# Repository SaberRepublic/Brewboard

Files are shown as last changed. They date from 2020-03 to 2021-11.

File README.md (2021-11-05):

# Brewboard
PCB files for the Saber Republic Brewboard

Format is EagleCAD schematic, board layout, and library 

Brewboard is a carrier board for an Arduino Nano, DFPlayer and GY-521 accelerometer. It is designed to make it easy and cheap to build a homebrew soundboard for your saber or other custom props. While it's not as small as other choices on the market it is cheap fully opensource and full-featured. You can use different firmware solutions or roll your own.

 - Connects Arduino Nano, DFPlayer, and GY-521
 - Supports Neo-Pixel and RGB/RGBW Star LEDs and string blades* (with added MOSFETs and resitors)
 - Uses 0805 resitors and sot23 MOSFETs to keep it's footprint small.

You can direct order a board from here:
[Saber Republic](https://saberrepublic.bigcartel.com)

Model Can be viewed and downloaded here:
[Brewboard model](https://sketchfab.com/3d-models/brewboard-v401-b3-2d1b7a565fd34a01af89348552af9d3d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)

There two choices for firmware:

[FX-SaberOS (opensource)](https://github.com/Protonerd/FX-SaberOS)

[STREAM (closedsource but very user friendly)](https://github.com/JakeS0ft/STREAM)

This is a video demo of Brewboard V2 in action.

Brewboard V2 (https://www.youtube.com/watch?v=12ZV0RvzIn0)

V2 Pinout diagrams.

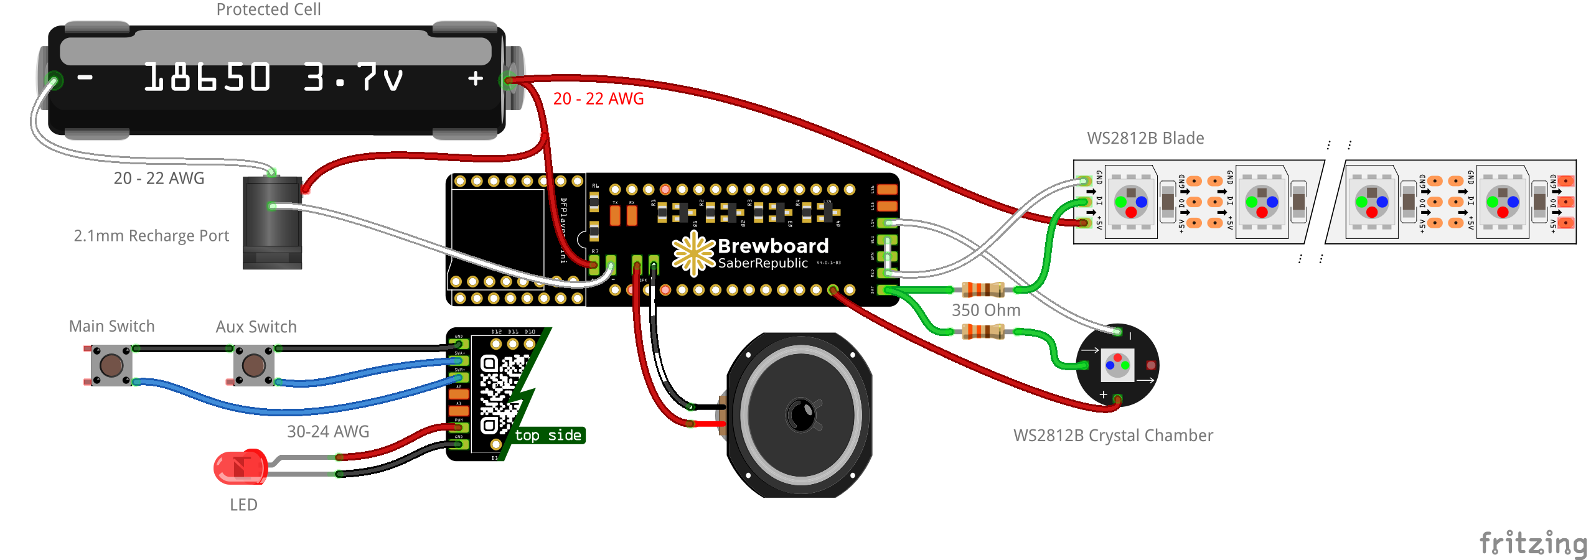
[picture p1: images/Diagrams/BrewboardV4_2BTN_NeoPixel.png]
NeoPixel Pinout


For more diagrams and Info Check the [Wiki](https://github.com/SaberRepublic/Brewboard/wiki)

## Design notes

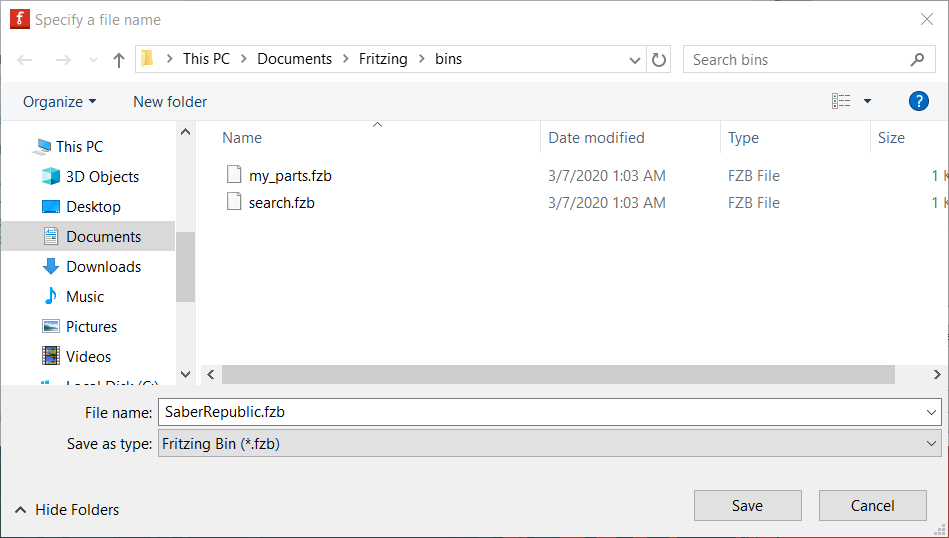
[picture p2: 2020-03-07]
images/Fritzing/5_SpecifyFileName.png

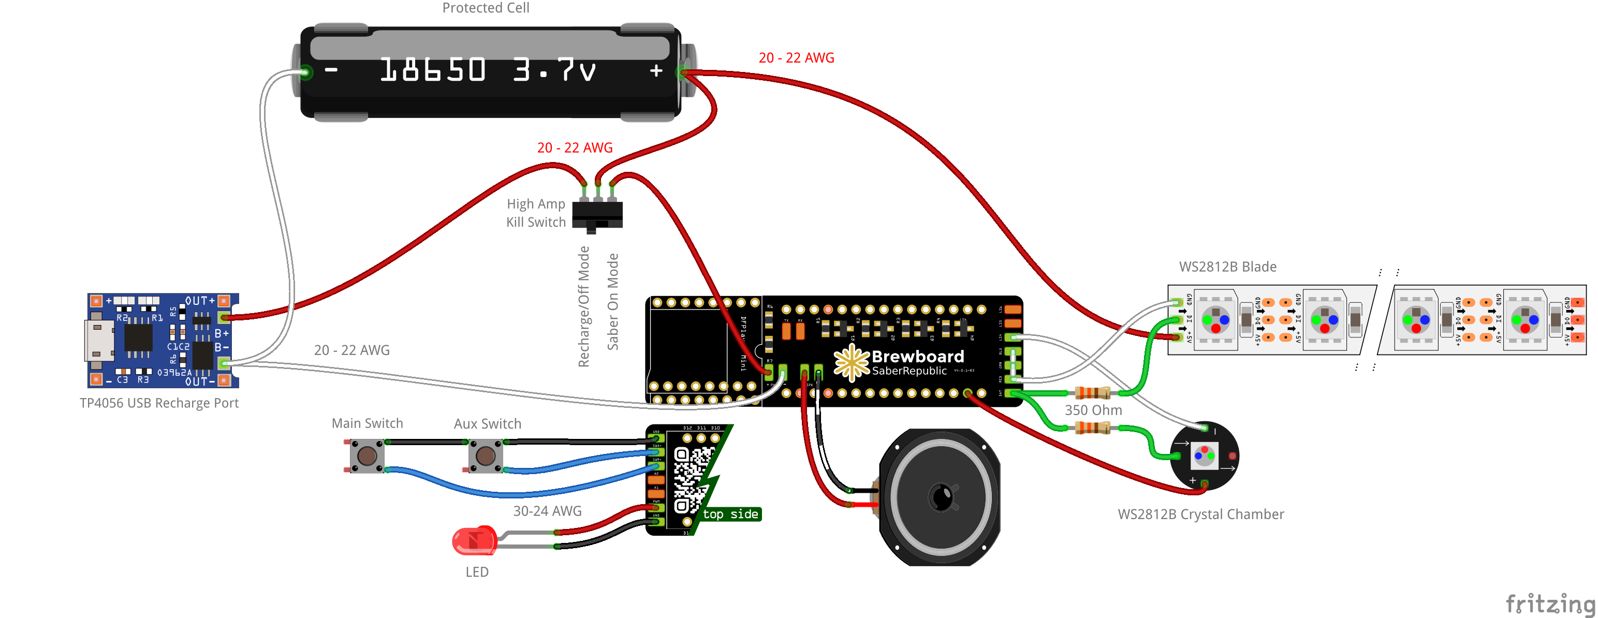
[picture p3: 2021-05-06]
images/Diagrams/BrewboardV4_2BTN_NeoPixel_TP4056.png

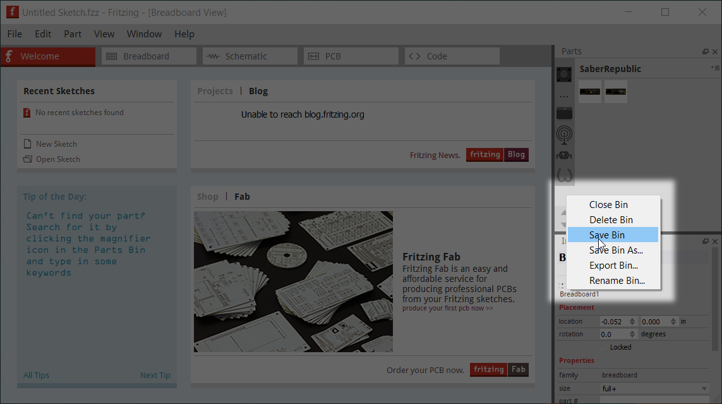
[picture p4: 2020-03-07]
images/Fritzing/4_SaveBin.png

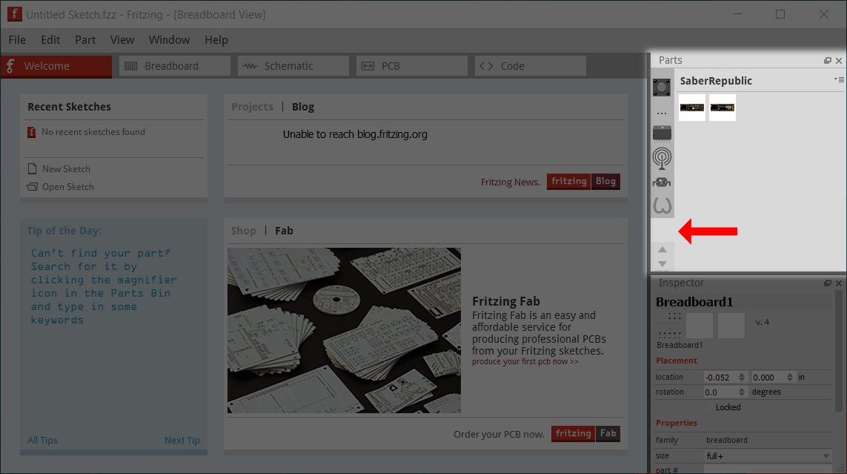
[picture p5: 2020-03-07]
images/Fritzing/3_BinLoaded.png

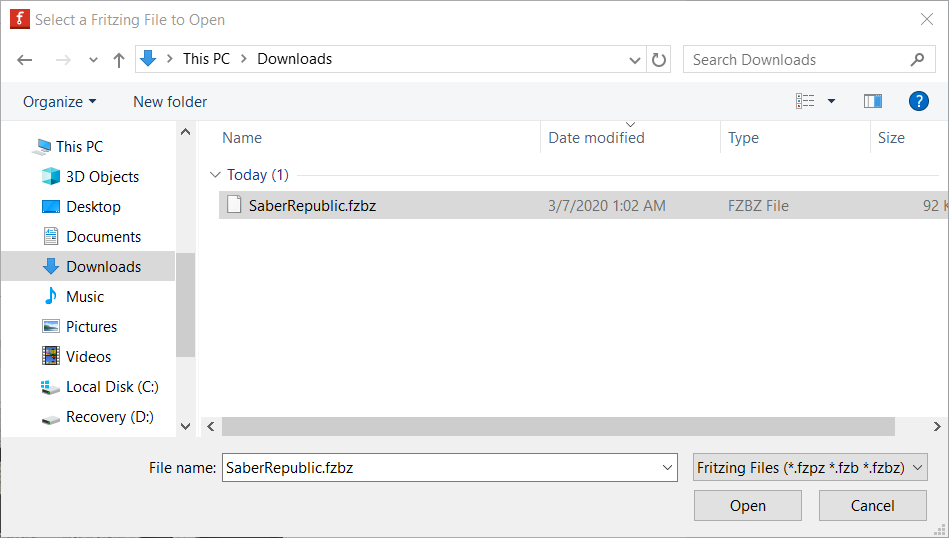
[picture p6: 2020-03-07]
images/Fritzing/2_SelectFritzingFiletoOpen.png

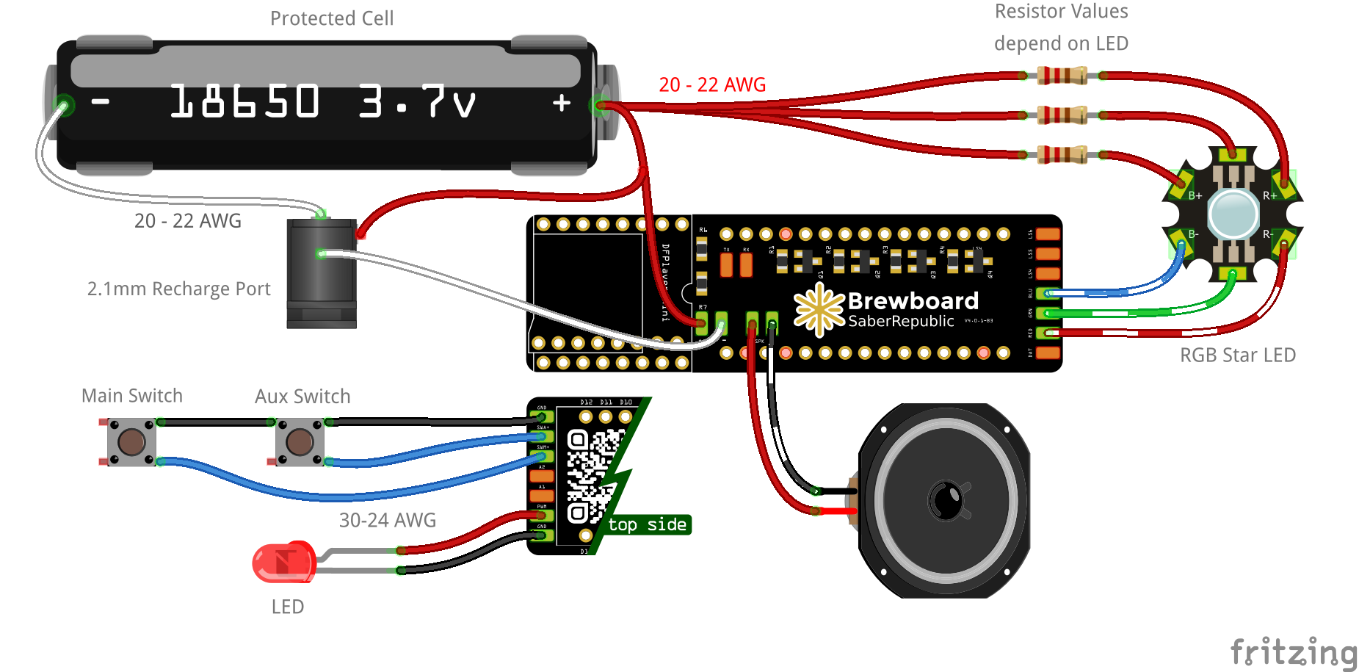
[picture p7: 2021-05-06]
images/Diagrams/BrewboardV4_2BTN_Star.png

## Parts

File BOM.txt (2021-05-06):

+-----+-----------------+----------------+---------+--------------------+---------------------------+
| Qty |      Value      |     Device     | Package |       Parts        |        Description        |
+-----+-----------------+----------------+---------+--------------------+---------------------------+
|   5 | 100k Ohms       | R-US_R0805     | R0805   | R1, R2, R3, R4, R6 | RESISTOR, American symbol |
|   1 | 470k Ohms       | R-US_R0805     | R0805   | R7                 | RESISTOR, American symbol |
|   4 | si2302cds-t1-e3 | MOSFET-NREFLOW | SOT23   | Q1, Q2, Q3, Q4     | N-Channel Mosfet          |
+-----+-----------------+----------------+---------+--------------------+---------------------------+

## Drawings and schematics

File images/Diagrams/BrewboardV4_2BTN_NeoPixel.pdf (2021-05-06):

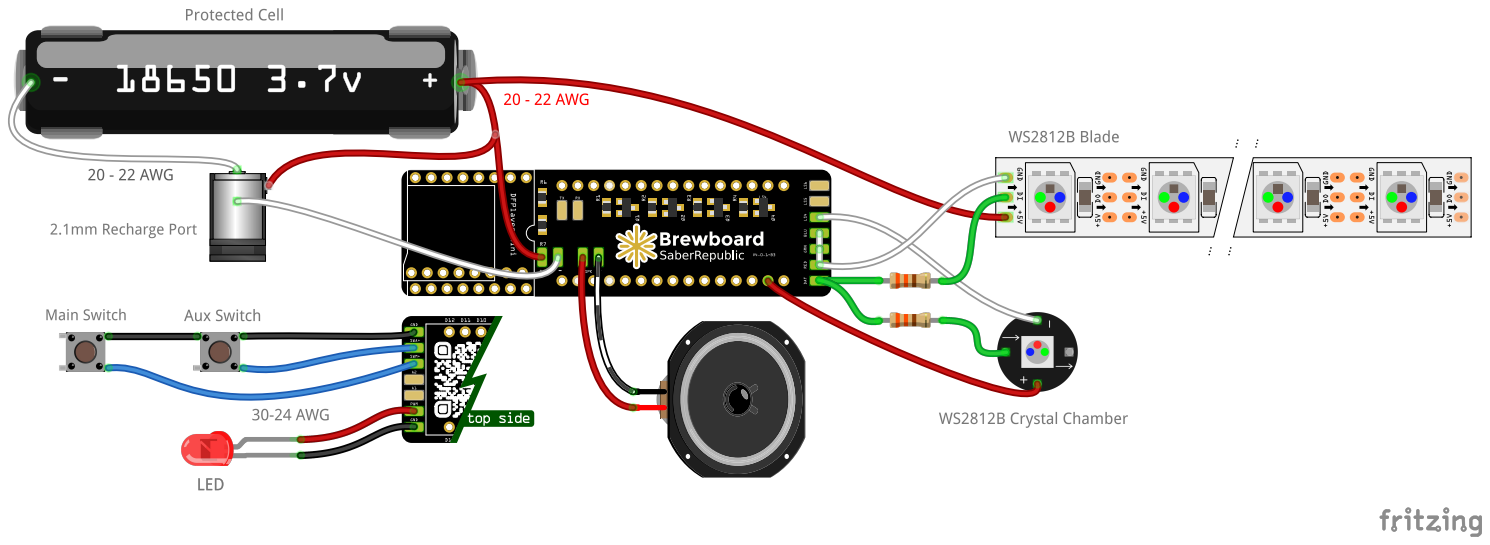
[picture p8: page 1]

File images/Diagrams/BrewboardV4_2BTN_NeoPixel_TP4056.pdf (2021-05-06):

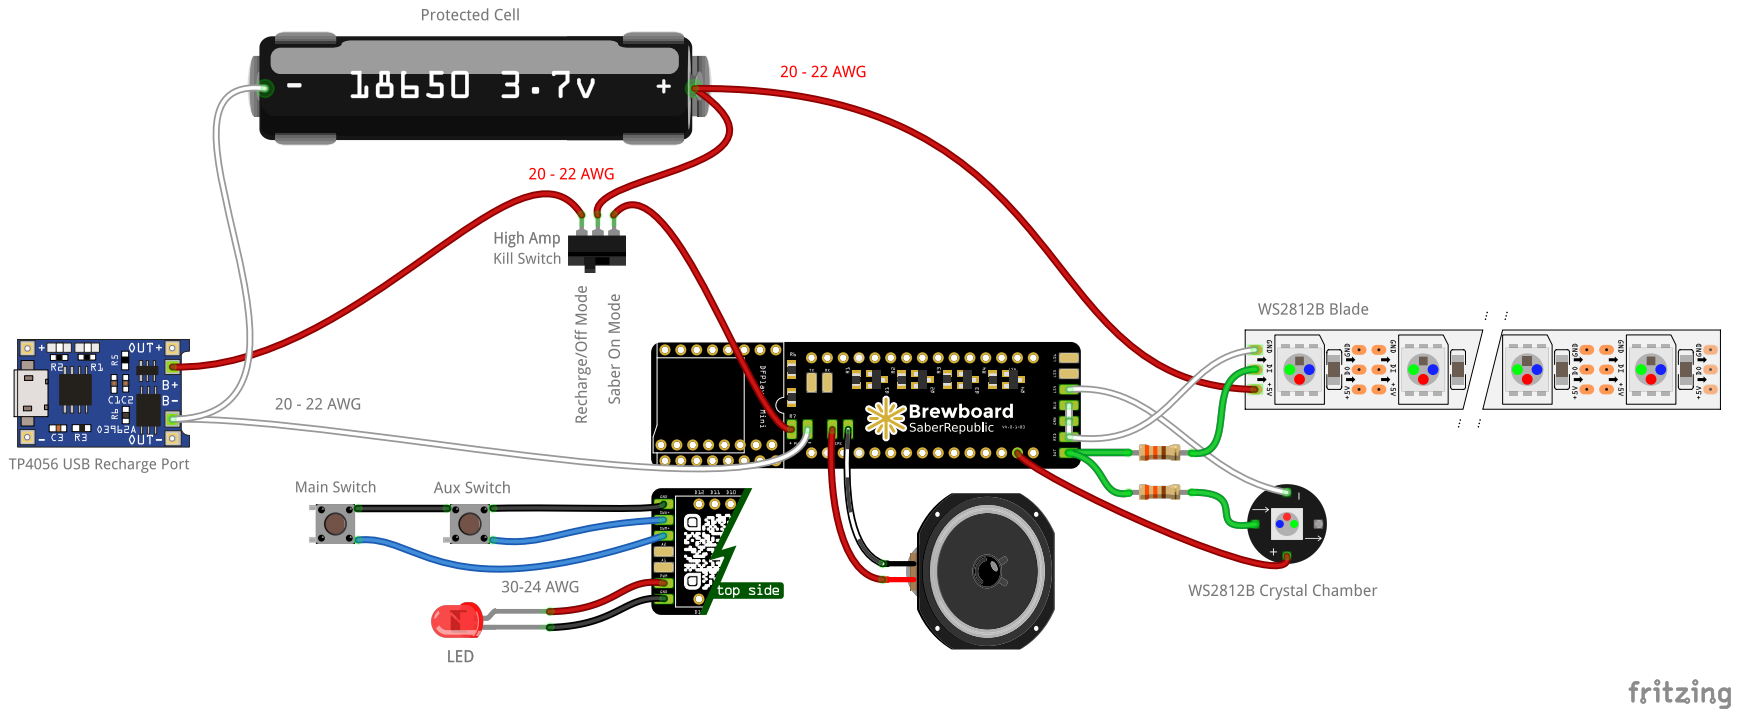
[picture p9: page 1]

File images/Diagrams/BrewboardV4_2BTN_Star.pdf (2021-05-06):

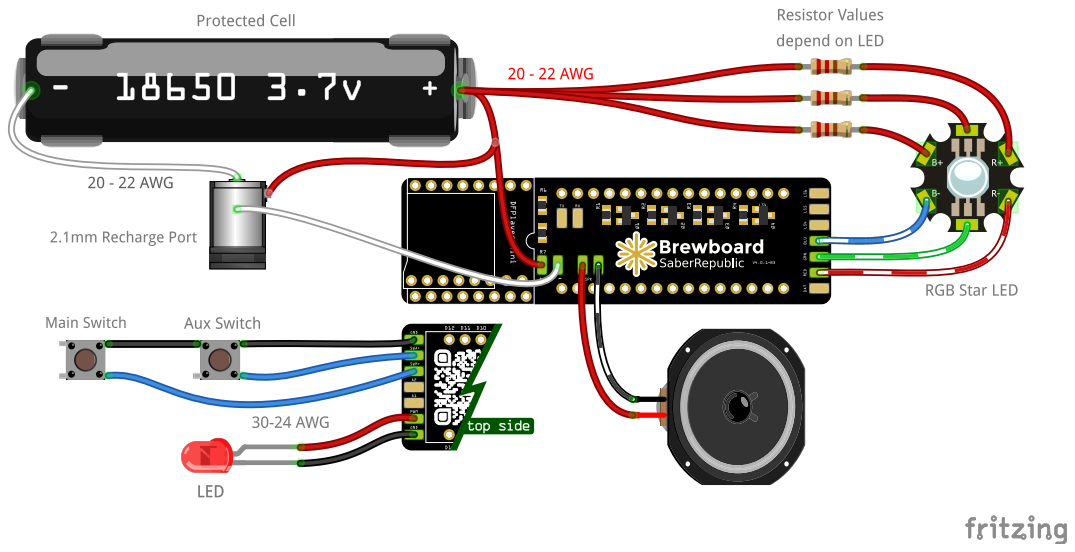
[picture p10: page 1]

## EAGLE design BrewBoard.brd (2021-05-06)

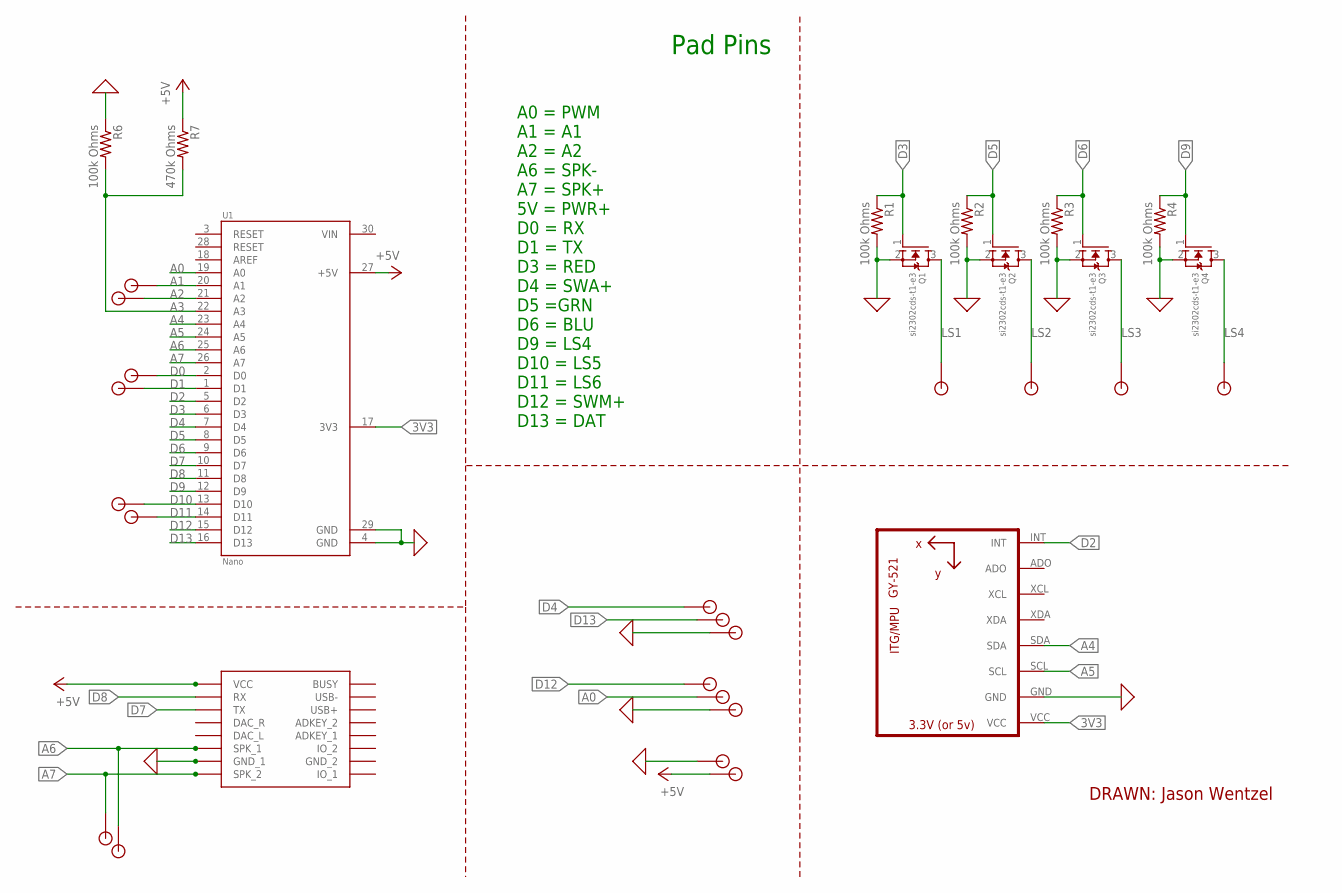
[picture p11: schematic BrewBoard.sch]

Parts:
LS1: SINGLE_ONE_SIDE_PAD; SOS_PAD
Q1, Q2, Q3, Q4: si2302cds-t1-e3; SOT23
R1, R2, R3, R4, R6: 100k Ohms; R0805
R7: 470k Ohms; R0805
SPK+: SINGLE_ONE_SIDE_PAD; SOS_PAD
U1: Nano; ARDUINO_NANO_OUT
U2: GY-521MPU6050; GY-521
U3: DFPLAYER
U$1, U$4, U$5, U$6, U$7, U$8, U$9, U$11, U$12, U$13, U$15, U$16, U$17, U$18, U$19, U$22, U$27, U$28: SINGLE_ONE_SIDE_PAD; SOS_PAD

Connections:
0: Q1.2 (S), Q2.2 (S), Q3.2 (S), Q4.2 (S), R1.2, R2.2, R3.2, R4.2, R6.1, U1.4 (GND), U1.29 (GND), U2.GND, U3.GND_1, U$13.P$1, U$17.P$1, U$27.P$1
3V3: U1.17 (3V3), U2.VCC
+5V: R7.1, U1.27 (+5V), U3.VCC, U$12.P$1
A0: U1.19 (A0), U$18.P$1
A1: U1.20 (A1), U$1.P$1
A2: U1.21 (A2), U$4.P$1
A3: R6.2, R7.2, U1.22 (A3)
A4: U1.23 (A4), U2.SDA
A5: U1.24 (A5), U2.SCL
A6: U1.25 (A6), U3.SPK1 (SPK_1), U$11.P$1
A7: SPK+.P$1, U1.26 (A7), U3.SPK2 (SPK_2)
D0: U1.2 (D0), U$5.P$1
D1: U1.1 (D1), U$6.P$1
D2: U1.5 (D2), U2.INT
D3: Q1.1 (G), R1.1, U1.6 (D3)
D4: U1.7 (D4), U$22.P$1
D5: Q2.1 (G), R2.1, U1.8 (D5)
D6: Q3.1 (G), R3.1, U1.9 (D6)
D7: U1.10 (D7), U3.TX
D8: U1.11 (D8), U3.RX
D9: Q4.1 (G), R4.1, U1.12 (D9)
D10: U1.13 (D10), U$8.P$1
D11: U1.14 (D11), U$9.P$1
D12: U1.15 (D12), U$19.P$1
D13: U1.16 (D13), U$28.P$1
LS1: LS1.P$1, Q1.3 (D)
LS2: Q2.3 (D), U$15.P$1
LS3: Q3.3 (D), U$16.P$1
LS4: Q4.3 (D), U$7.P$1
VIN: U1.30 (VIN)

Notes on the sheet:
DRAWN: Jason Wentzel
Pad Pins
A0 = PWM A1 = A1 A2 = A2 A6 = SPK- A7 = SPK+ 5V = PWR+ D0 = RX D1 = TX D3 = RED D4 = SWA+ D5 =GRN D6 = BLU D9 = LS4 D10 = LS5 D11 = LS6 D12 = SWM+ D13 = DAT

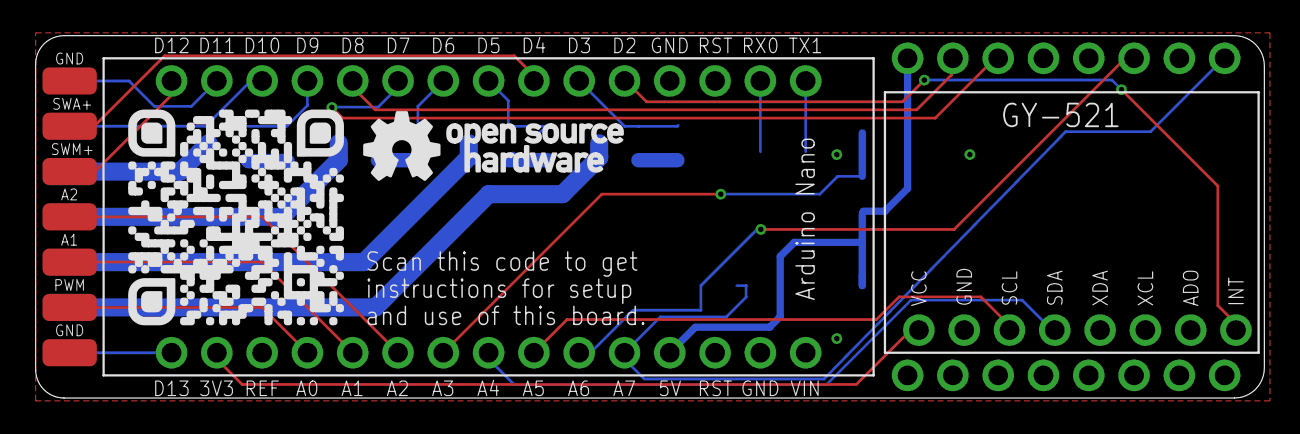
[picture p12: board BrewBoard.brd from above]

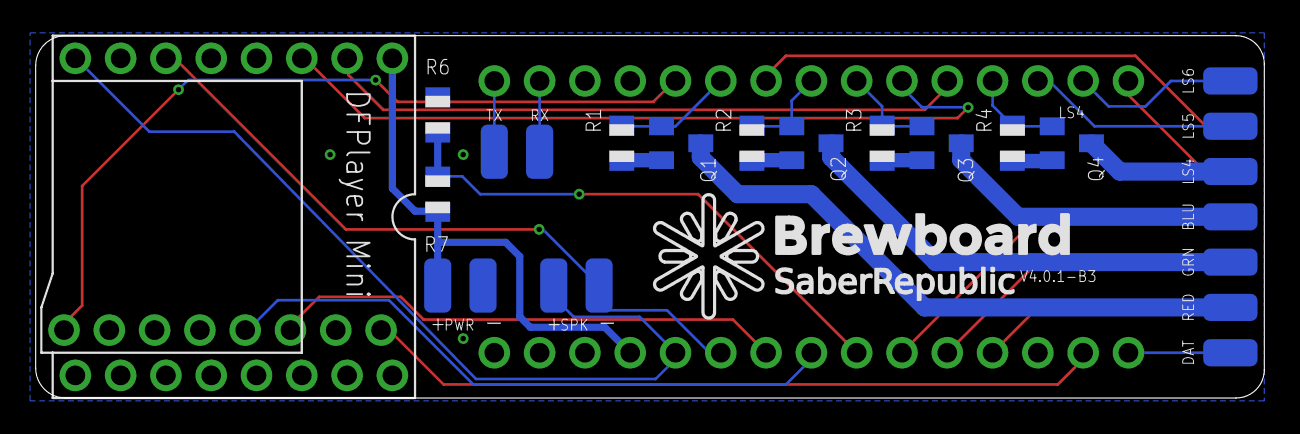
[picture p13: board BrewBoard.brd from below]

Board: 2 copper layers, 68.9 x 20.3 mm, 36 parts (24 on the bottom side), 29 nets.

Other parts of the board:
U$2: BREWBOARD_GOLDSTAR_SM
U$3: OSHW_FULL_TOP
U$31: BREWBOARD_QR_CODE

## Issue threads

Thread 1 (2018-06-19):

BOM Specifics

justgrumpy, 2018-06-19:
Can the BOM contain more specifics? For instance with the resistors what is the power rating, tolerance, etc.?

JCWentzel, 2019-04-10:
I will be converting the BOM to CSV format and adding more detail soon.

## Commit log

2018-03-05 Renders
    Adding some renders untill proper boards show up
2018-03-05 Update README.md
    Added a Render of the board
2018-04-22 Design Files
    Adding design files for the V2 Brewboard
    [BrewBoard.brd, BrewBoard.sch]
2018-04-30 Board updated to v2.0.1
    Added thicker traces for Power and Ground
    Added pinout lables
    Updated Read me with Frizting Diagrams for Star and NeoPixel LEDs
    [BrewBoard.brd]
2018-04-30 Added BOM
    Added BOM and Schematic render as well as a small update to the readme.
2018-09-27 Updated BOM
    Updated MOSFETs and added resistor wattage.
2019-03-19 Basic Wiring Diagrams
    New wiring diagrams for documentation.
    Labeling old diagrams as V2 to make it clear what version they are for
2019-03-19 Logos and Board images
    Added Logos and Board images
2019-05-29 Brewboard V3 Update
    Adding New Version 3 Update of Brewboard
    Feature/Change List;
    - Interrupt mode is now available for clashes.
    - All extra Pins have pads (for folks that want to experiment and add features).
    - LED Power Traces are now able to handle a total of 7.8A so Pixel Blades can be safely hooked up to MOSFETs (less drain in deepsleep).
    - Power Traces for Pixels removed! Pixel Blade can be wired directly from the battery Positive, and to two or three of the RGB MOSFET pads as mentioned above.
    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
    [BrewBoard.brd, BrewBoard.sch]
2019-08-17 New 3D Files
    Added Some Suport 3D files for folks that want to design their own chassis systems.
    [BrewBoard PCB Component v2.f3d]
2021-05-06 BOM updated
    Replaced html version of BOM with CSV and Updated for V4
    [BOM.csv]
2021-05-06 Updated to V4
    Updated source files to V4 and deleted PDF version of Schematic
    [BrewBoard.brd, BrewBoard.sch]
2021-05-06 Old Models Removed
    Removed old models and added link to the readme for the new model
    [BrewBoard PCB Component v2.f3d]
